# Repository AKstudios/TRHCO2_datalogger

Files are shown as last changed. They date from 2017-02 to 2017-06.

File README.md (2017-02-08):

# T/RH/CO2 data logger
A temperature, relative humidity and carbon dioxide data logger that stores time-stamped data in a microSD card at specific logging intervals.

<p align="center">
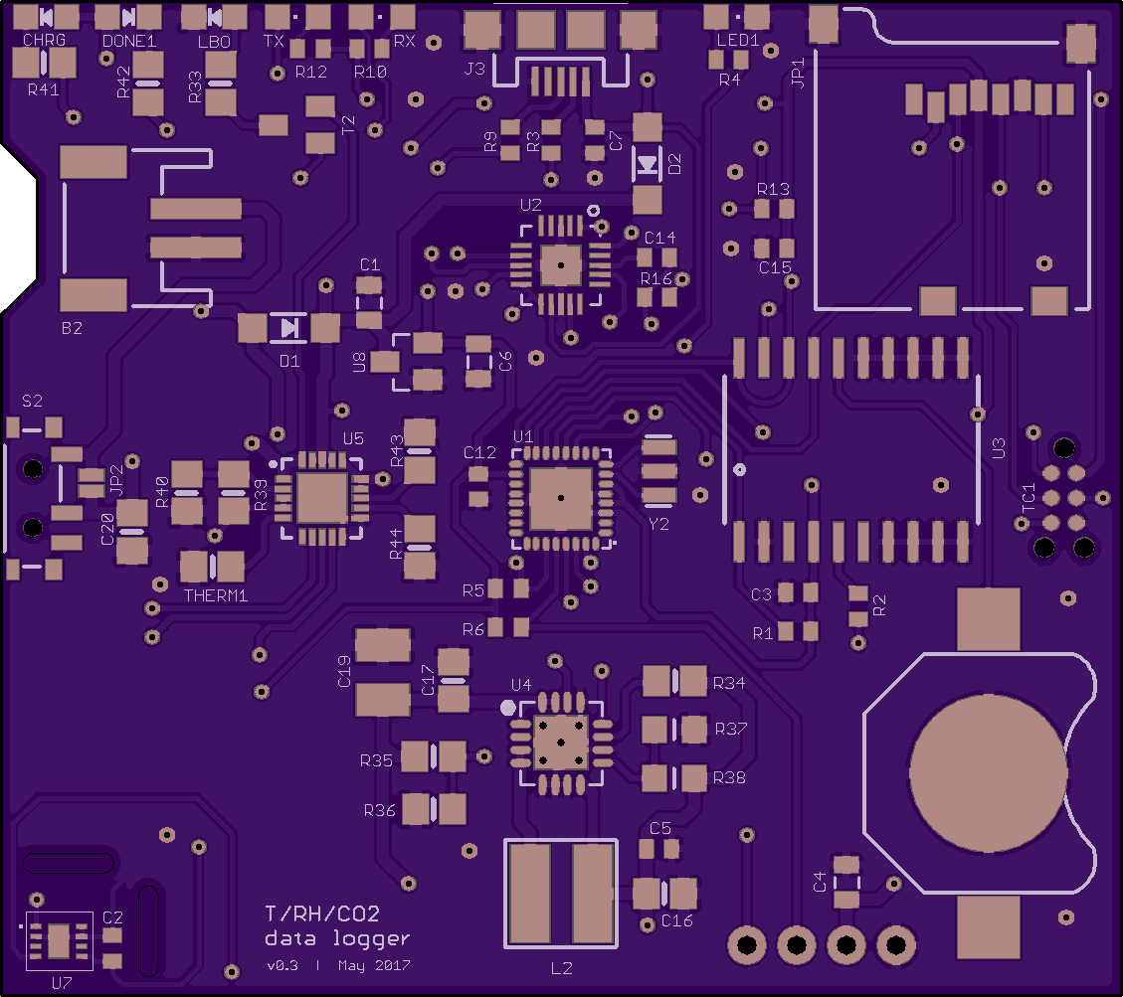
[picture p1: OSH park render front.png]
PIR datalogger - front
  
  <br></br>
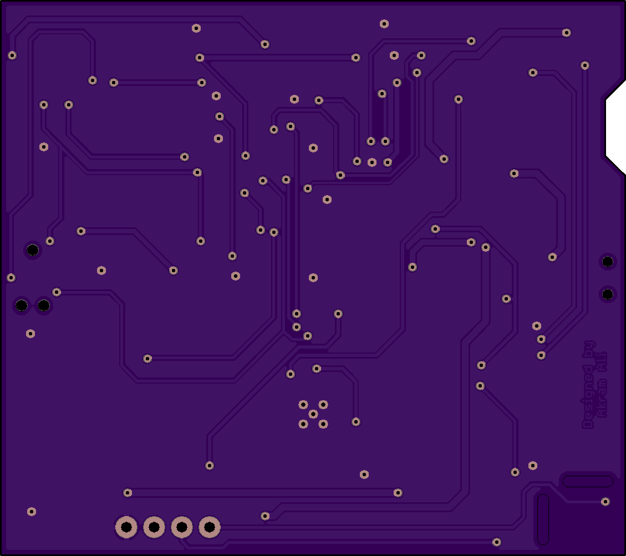
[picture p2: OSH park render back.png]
PIR datalogger - back
  
</p>

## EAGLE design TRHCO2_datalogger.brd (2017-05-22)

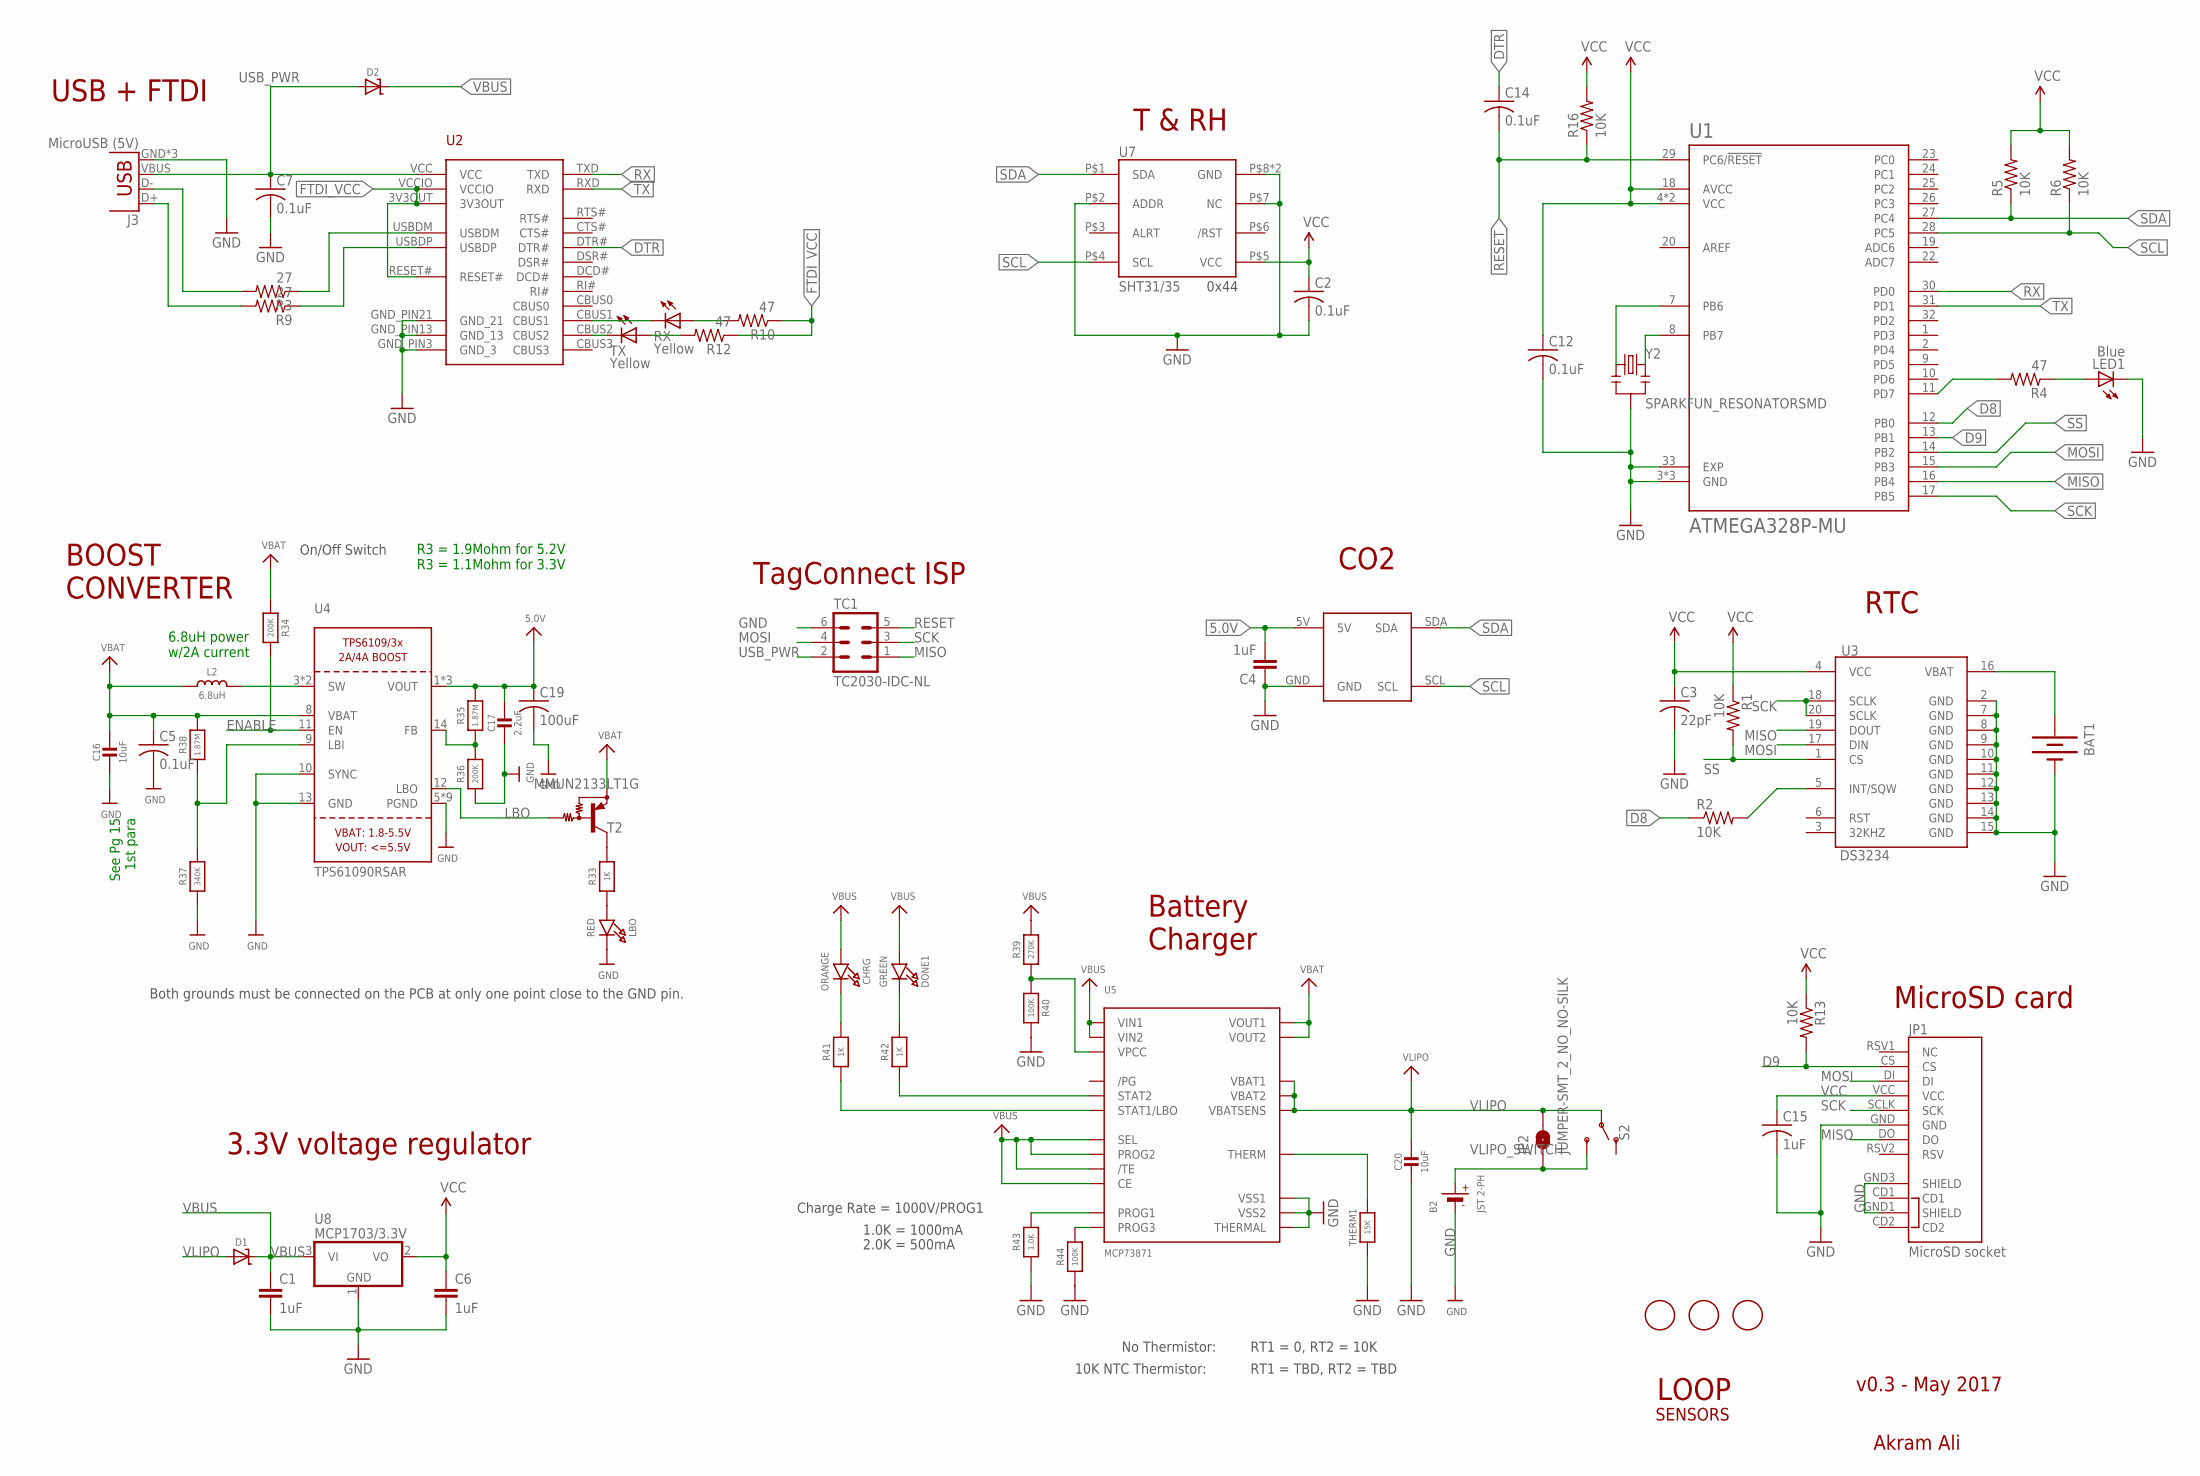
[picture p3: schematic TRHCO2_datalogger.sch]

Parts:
B2: JST 2-PH; JSTPH2
BAT1: BATTERY12MM; BATTCON_12MM; MPN 3000
C1, C4, C6: 1uF; 0805; MPN CC0805KKX7R7BB105
C2, C5, C7, C12, C14: 0.1uF; C0402
C3: 22pF; C0402
C15: 1uF; C0402
C16, C20: 10uF; 0805-NO
C17: 2.2uF; 0805-NO
C19: 100uF; C1210
CHRG: ORANGE; CHIPLED_0805_NOOUTLINE
D1, D2: MICROBUILDER_DIODE-SCHOTTKYSOD-123; MICROBUILDER_SOD-123
DONE1: GREEN; CHIPLED_0805_NOOUTLINE
J3: MicroUSB (5V); USB-MICROB; MPN CONN-09505
JP1: MicroSD socket; MICRO-SD-SOCKET-PP
JP2: JUMPER-SMT_2_NO_NO-SILK; SMT-JUMPER_2_NO_NO-SILK
L2: 6.8uH; INDUCTOR_5X5MM_TDK_VLC5045
LBO: RED; CHIPLED_0805_NOOUTLINE
LED1: Blue; CHIPLED_0805; MPN 150080BS75000
R1, R2, R5, R6, R13, R16: 10K; R0402
R3, R9: 27; R0402
R4, R10, R12: 47; R0402
R33, R41, R42: 1K; 0805-NO
R34, R36: 200K; 0805-NO
R35: 1.87M; 0805-NO
R37: 340K; _0805MP
R38: 1.87M; _0805MP
R39: 270K; 0805-NO
R40, R44: 100K; 0805-NO
R43: 1.0K; 0805-NO
RX: Yellow; CHIPLED_0805; MPN LG R971-KN-1
S2: SWITCH-SPDT-SMD-RIGHT-ANGLE; SWITCH_SPST_SMD_A
T2: MMUN2133LT1G; SC59-BEC
TC1: TC2030-IDC-NL
THERM1: 15K; 0805-NO
TX: Yellow; CHIPLED_0805; MPN LH R974-LP-1
U1: ATMEGA328P-MU; QFN50P500X500X100-33N
U2: FT231XQ-R; FTDI_FT231XQ-R_PACKAGE; MPN FT231XQ-R
U3: DS3234; MPN DS3234S#
U4: TPS61090RSAR; PVQFN-16
U5: MCP73871; QFN20_4MM
U6: K30-CO2-I2C
U7: SHT31/35; SHT3X; MPN SHT31-DIS-B
U8: MCP1703/3.3V; SOT23; MPN MCP1703T-2502E/CB
U$1, U$2, U$3: FIDUCIAL; FIDUCIAL_1MM
Y2: SPARKFUN_RESONATORSMD; SPARKFUN_RESONATOR-SMD

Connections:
5.0V: C4.2, C17.1, C19.1, R35.2, U4.1 (VOUT), U4.15 (VOUT), U4.16 (VOUT), U6.5V
D8: R2.1, U1.12 (PB0)
D9: JP1.CS, R13.2, U1.13 (PB1)
DTR: C14.1, U2.DTR#
ENABLE: R34.2, U4.11 (EN)
FTDI_VCC: R10.1, R12.1, U2.3V3OUT, U2.RESET#, U2.VCCIO
GND: B2.1 (-), BAT1.GND (-), C1.2, C2.2, C3.2, C4.1, C5.2, C6.2, C7.2, C12.2, C15.2, C16.2, C17.2, C19.2, C20.2, J3.GND, J3.MT1 (GND), J3.MT2 (GND), JP1.GND, JP1.GND1 (SHIELD), JP1.GND3 (SHIELD), LBO.C, LED1.C, R36.1, R37.1, R40.2, R43.1, R44.1, TC1.6, THERM1.1, U1.3 (GND), U1.5 (GND), U1.21 (GND), U1.33 (EXP), U2.GND_PIN3 (GND_3), U2.GND_PIN13 (GND_13), U2.GND_PIN21 (GND_21), U3.2 (GND), U3.7 (GND), U3.8 (GND), U3.9 (GND), U3.10 (GND), U3.11 (GND), U3.12 (GND), U3.13 (GND), U3.14 (GND), U3.15 (GND), U4.5 (PGND), U4.6 (PGND), U4.7 (PGND), U4.10 (SYNC), U4.13 (GND), U4.P$18 (PGND), U4.P$19 (PGND), U4.P$20 (PGND), U4.P$21 (PGND), U4.P$22 (PGND), U4.THERMAL (PGND), U5.P$10 (VSS1), U5.P$11 (VSS2), U5.P$21 (THERMAL), U6.GND, U7.P$2 (ADDR), U7.P$7 (NC), U7.P$8 (GND), U7.PAD (GND), U8.1 (GND), Y2.2
LBO: T2.B, U4.12 (LBO)
MISO: JP1.DO, TC1.1, U1.16 (PB4), U3.19 (DOUT)
MOSI: JP1.DI, TC1.4, U1.15 (PB3), U3.17 (DIN)
unnamed: R4.2, U1.11 (PD7)
unnamed: R2.2, U3.5 (INT/SQW)
unnamed: LED1.A, R4.1
unnamed: U1.8 (PB7), Y2.3
unnamed: U1.7 (PB6), Y2.1
unnamed: L2.P$2 (2), U4.3 (SW), U4.4 (SW)
unnamed: R37.2, R38.1, U4.9 (LBI)
unnamed: BAT1.PWR@1 (+), U3.16 (VBAT)
unnamed: LBO.A, R33.1
unnamed: RX.C, U2.CBUS1
unnamed: TX.C, U2.CBUS2
unnamed: R3.1, U2.USBDM
unnamed: R9.1, U2.USBDP
unnamed: R10.2, RX.A
unnamed: R35.1, R36.2, U4.14 (FB)
unnamed: R12.2, TX.A
unnamed: R33.2, T2.C
unnamed: R39.1, R40.1, U5.P$2 (VPCC)
unnamed: J3.D-, R3.2
unnamed: J3.D+, R9.2
unnamed: R42.1, U5.P$7 (STAT2)
unnamed: R41.1, U5.P$8 (STAT1/LBO)
unnamed: R43.2, U5.P$13 (PROG1)
unnamed: THERM1.2, U5.P$5 (THERM)
unnamed: DONE1.C, R42.2
unnamed: CHRG.C, R41.2
unnamed: R44.2, U5.P$12 (PROG3)
RESET: C14.2, R16.1, TC1.5, U1.29 (PC6/!RESET)
RX: U1.30 (PD0), U2.TXD
SCK: JP1.SCLK (SCK), TC1.3, U1.17 (PB5), U3.18 (SCLK), U3.20 (SCLK)
SCL: R6.1, U1.28 (PC5), U6.SCL, U7.P$4 (SCL)
SDA: R5.1, U1.27 (PC4), U6.SDA, U7.P$1 (SDA)
SS: R1.2, U1.14 (PB2), U3.1 (CS)
TX: U1.31 (PD1), U2.RXD
USB_PWR: C7.1, D2.A, J3.VBUS, TC1.2, U2.VCC
VBAT: C5.1, C16.1, L2.P$1 (1), R34.1, R38.2, T2.E, U4.8 (VBAT), U5.P$1 (VOUT1), U5.P$20 (VOUT2)
VBUS: C1.1, CHRG.A, D1.C, D2.C, DONE1.A, R39.2, U5.P$3 (SEL), U5.P$4 (PROG2), U5.P$9 (/TE), U5.P$17 (CE), U5.P$18 (VIN1), U5.P$19 (VIN2), U8.3 (VI)
VCC: C2.1, C3.1, C6.1, C12.1, C15.1, JP1.VCC, R1.1, R5.2, R6.2, R13.1, R16.2, U1.4 (VCC), U1.6 (VCC), U1.18 (AVCC), U3.4 (VCC), U7.P$5 (VCC), U8.2 (VO)
VLIPO: C20.1, D1.A, JP2.2, S2.2, U5.P$14 (VBAT1), U5.P$15 (VBAT2), U5.P$16 (VBATSENS)
VLIPO_SWITCH: B2.2 (+), JP2.1, S2.3 (S)

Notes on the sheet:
T & RH
3.3V voltage regulator
LOOP
Akram Ali
USB + FTDI
0x44
CO2
MicroSD card
RTC
v0.3 - May 2017
SENSORS
Both grounds must be connected on the PCB at only one point close to the GND pin.
On/Off Switch
See Pg 15 1st para
6.8uH power w/2A current
R3 = 1.9Mohm for 5.2V R3 = 1.1Mohm for 3.3V
Charge Rate = 1000V/PROG1
1.0K = 1000mA
2.0K = 500mA
No Thermistor:
10K NTC Thermistor:
RT1 = 0, RT2 = 10K
RT1 = TBD, RT2 = TBD
BOOST CONVERTER
Battery Charger
TagConnect ISP

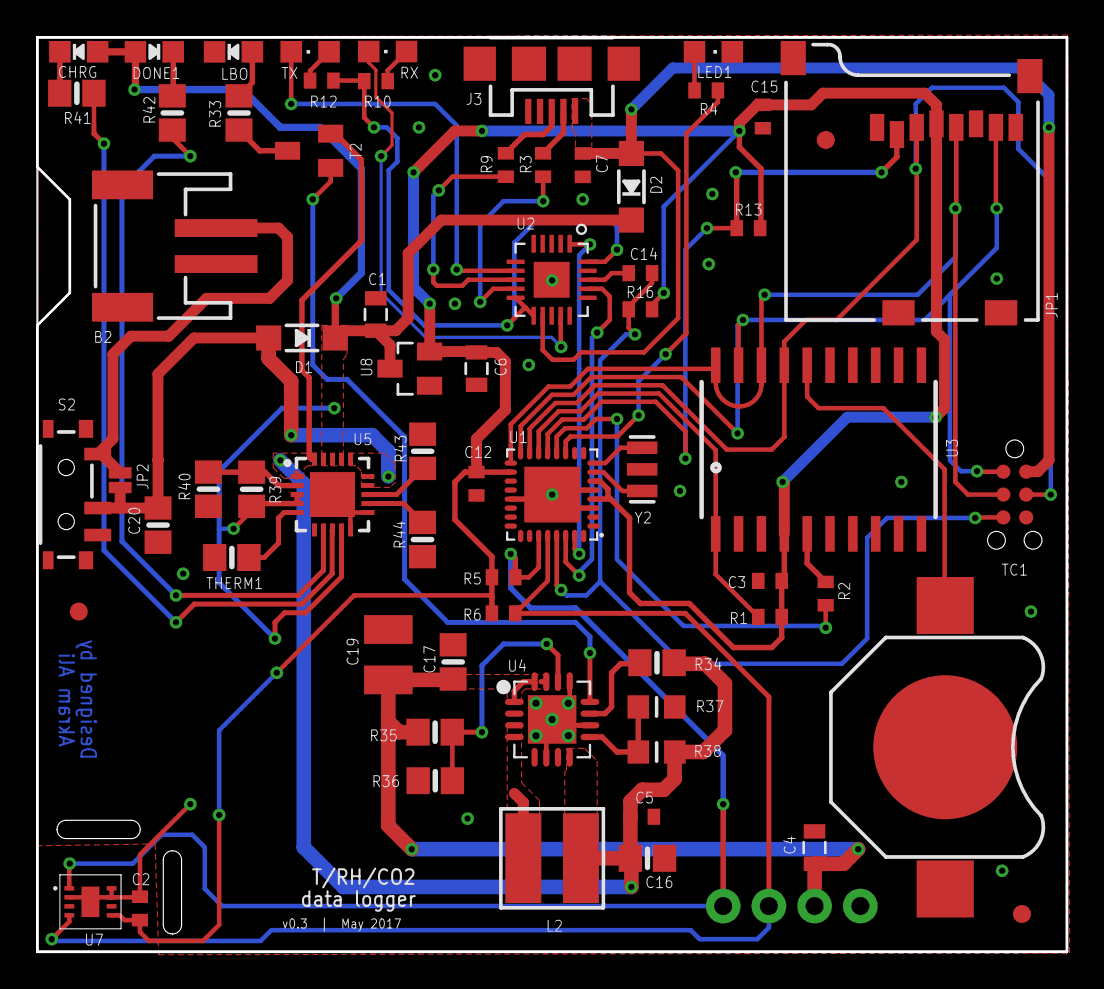
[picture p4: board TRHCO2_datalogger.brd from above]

Board: 2 copper layers, 57.2 x 50.8 mm, 67 parts (0 on the bottom side), 50 nets.

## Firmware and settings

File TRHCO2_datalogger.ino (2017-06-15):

// OSBSS T/RH/CO2 data logger based on SenseAir K-30 1% CO2 sensor and Sensirion SHT35 sensor
// read interval stored in config.txt
// Last edited on June 15, 2017 - Arduino IDE 1.8.2, Latest SdFat library

#include <EEPROM.h>
#include <Wire.h>
#include <SPI.h>
#include <DS3234lib3.h>         // https://github.com/OSBSS/DS3234lib3
#include <PowerSaver.h>         // https://github.com/OSBSS/PowerSaver
#include "SdFat.h"              // https://github.com/greiman/SdFat
#include "Adafruit_SHT31.h"     // https://github.com/adafruit/Adafruit_SHT31

// Launch Variables   ******************************
long interval = 30;  // set logging interval in SECONDS, eg: set 300 seconds for an interval of 5 mins
int dayStart = 14, hourStart = 13, minStart = 41;    // define logger start time: day of the month, hour, minute
char filename[15] = "data.csv";    // Set filename Format: "12345678.123". Cannot be more than 8 characters in length, contain spaces or begin with a number
int data; // read each byte of data from sd card and store here

// Global objects and variables   ******************************
Adafruit_SHT31 sht31 = Adafruit_SHT31();
PowerSaver chip;  	// declare object for PowerSaver class
DS3234 RTC;    // declare object for DS3234 class
SdFat sd;
SdFile myFile;

//#define POWER 3    // pin 3 supplies power to microSD card breakout
#define LED 7  // pin 7 controls LED
int chipSelect = 9; // pin 9 is CS pin for MicroSD breakout

int CO2ppm = 0;
int _CO2ppm;

// ISR ****************************************************************
ISR(PCINT0_vect)  // Interrupt Vector Routine to be executed when pin 8 receives an interrupt.
{
  //PORTB ^= (1<<PORTB1);
  asm("nop");
}

// setup ****************************************************************
void setup()
{
  Serial.begin(19200); // open serial at 19200 bps
  Serial.flush(); // clear the buffer
  delay(5);
  
  Serial.println("Setup");
  delay(10);
  
  pinMode(LED, OUTPUT); // set output pins
  Wire.begin();  // initialize I2C using Wire.h library
  delay(1);    // give some delay to ensure things are initialized properly

  if (! sht31.begin(0x44))  // Set to 0x45 for alternate i2c addr
  {   
    Serial.println("Couldn't find SHT31/35");
    delay(10);
  }
  
  Serial.println(RTC.timeStamp());    // get date and time from RTC
  delay(10);

  if(!sd.begin(chipSelect, SPI_HALF_SPEED))  // initialize microSD card
  {
    SDcardError(3);
  }
  else
  {
    // open the file for write at end like the Native SD library
    if(!myFile.open(filename, O_RDWR | O_CREAT | O_AT_END))
    {
      SDcardError(2);
    }

    else
    {    
      myFile.println();
      myFile.println("Date/Time,Temp(C),RH(%),CO2(ppm)");
      myFile.println();
      myFile.close();
      
      digitalWrite(LED, HIGH);
      delay(10);
      digitalWrite(LED, LOW);
    }
  }
  
  if(!myFile.open("config.txt", O_READ))  // open config.txt and read logging interval
  {
    Serial.println("config.txt file error. Setting default interval to 30 seconds.");
    delay(50);
  }

  else
  {
    char interval_array[5]; // should be able to store 5 digit maximum (86,400 seconds = 24 hours)
    int i=0; // index of array
    long _interval;  // logging interval read from file
    boolean error_flag = false;
    
    while(1)
    {
      data = myFile.read();  // read next byte in file
      
      if(data < 0)  // if no bytes remaining, myFile.read() returns -1
        break;      // exit loop

      if(data >= 48 && data <= 57) // check if data is digits ONLY (between 0-9). ASCII value of 0 = 48; 9 = 57
        interval_array[i] = (char)data;  // store digit in char array
      else  // if any other charecter other than numbers 0-9
      {
        error_flag = true;
        break;
      }
      
      i++; // increment index of array by 1
      if(i>5)  // only read the first 5 digits in file. Ignore all other values
        break;
    }
    myFile.close();  // close file - very important!
    sscanf(interval_array, "%ld", &_interval);  // "%ld" will convert array to long (use "%d" to convert to int)
    
    if(_interval <= 0 || _interval > 86400 || error_flag == true)
    {
      Serial.println("Incorrect format or out of bounds. Must be a number between 1 and 86,400 seconds. Setting default interval to 30 seconds.");
      delay(50);
    }
    else
    {
      interval = _interval;
      Serial.print("New logging interval set: ");
      Serial.println(interval);
      delay(50);
    }
  }
  RTC.setNewAlarm(interval);
  chip.sleepInterruptSetup();    // setup sleep function on the ATmega328p. Power-down mode is used here
  delay(10);
}


// loop ****************************************************************
void loop()
{  
  chip.turnOffADC();    // turn off ADC to save power
  chip.turnOffSPI();  // turn off SPI bus to save power
  chip.turnOffWDT();  // turn off WatchDog Timer to save power (does not work for Pro Mini - only works for Uno)
  chip.turnOffBOD();    // turn off Brown-out detection to save power
  
  
  chip.goodNight();    // put processor in extreme power down mode - GOODNIGHT!
                       // this function saves previous states of analog pins and sets them to LOW INPUTS
                       // average current draw on Mini Pro should now be around 0.195 mA (with both onboard LEDs taken out)
                       // Processor will only wake up with an interrupt generated from the RTC, which occurs every logging interval
                       
  chip.turnOnADC();    // enable ADC after processor wakes up
  chip.turnOnSPI();   // turn on SPI bus once the processor wakes up
  delay(1);    // important delay to ensure SPI bus is properly activated
  
  RTC.alarmFlagClear();    // clear alarm flag
  
  RTC.checkDST();  // check and account for Daylight Saving Time in US

  String time = RTC.timeStamp();    // get date and time from RTC
  Serial.println(time);
  delay(10);
  
  float t = sht31.readTemperature();
  float h = sht31.readHumidity();
  
  CO2ppm = GetCO2(0x68); // default address for K-30 CO2 sensor is 0x68
  
  // account for dropped values
  if(CO2ppm > 0)
    _CO2ppm = CO2ppm;
  if(CO2ppm <=0)
    CO2ppm = _CO2ppm;

  Serial.print("Temperature: ");
  Serial.print(t);
  Serial.println(" C");
  
  Serial.print("Humidity: ");
  Serial.print(h); 
  Serial.println(" %");
  
  Serial.print("CO2: ");
  Serial.print(CO2ppm);
  Serial.println(" ppm");
  
  Serial.println();
  delay(50); // give some delay to ensure CO2 data is properly received from sensor
  

  if(!sd.begin(chipSelect, SPI_HALF_SPEED))
  {
    SDcardError(3);
  }
  else
  {
    if(!myFile.open(filename, O_RDWR | O_CREAT | O_AT_END))
    {
      SDcardError(2);
    }
  
    else
    {
      myFile.print(time);
      myFile.print(",");
      myFile.print(t);
      myFile.print(",");
      myFile.print(h);
      myFile.print(",");
      myFile.println(CO2ppm);
      myFile.close();
      
      digitalWrite(LED, HIGH);
      delay(10);
      digitalWrite(LED, LOW);
    }
  }
  
  RTC.setNextAlarm();      //set next alarm before sleeping
  delay(1);
}

// Get CO2 concentration ****************************************************************
int GetCO2(int address)
{
  byte recieved[4] = {0,0,0,0}; // create an array to store bytes received from sensor
  
  Wire.beginTransmission(address);
  Wire.write(0x22);
  Wire.write(0x00);
  Wire.write(0x08);
  Wire.write(0x2A);
  Wire.endTransmission();
  delay(20); // give delay to ensure transmission is complete
  
  Wire.requestFrom(address,4);
  delay(10);
  
  byte i=0;
  while(Wire.available())
  {
    recieved[i] = Wire.read();
    i++;
  }
  
  byte checkSum = recieved[0] + recieved[1] + recieved[2];
  CO2ppm = (recieved[1] << 8) + recieved[2];
  
  if(checkSum == recieved[3])
    return CO2ppm;
  else
    return -1;
}

// SD card Error response ****************************************************************
void SDcardError(int n)
{
    for(int i=0;i<n;i++)   // blink LED 3 times to indicate SD card write error; 2 to indicate file read error
    {
      digitalWrite(LED, HIGH);
      delay(50);
      digitalWrite(LED, LOW);
      delay(150);
    }
}

//****************************************************************

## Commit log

2017-01-13 Added EAGLE files
    [TRHCO2_datalogger.brd, TRHCO2_datalogger.sch]
2017-01-17 Completed v0.1 design
    Routed all traces
    [TRHCO2_datalogger.brd, TRHCO2_datalogger.sch]
2017-01-18 Added D battery input headers
    Requires boost converter (https://www.sparkfun.com/products/10255) to allow 2 D batteries to supply at least 3V and get output 5V, 500mA
    [TRHCO2_datalogger.brd, TRHCO2_datalogger.sch]
2017-01-19 Traces adjusted
    Cleared some spacing between traces and vias
    Added MPN for some components
    [TRHCO2_datalogger.brd, TRHCO2_datalogger.sch]
2017-01-19 Minor fixes
    [TRHCO2_datalogger.brd, TRHCO2_datalogger.sch]
2017-02-08 v0.2 - Major fixes
    - Flipped header for LiPo boost. + and - are now facing up
    - Added pullup on DS3234 clock - so there is no interference while
    flashing bootloader (can be removed by desoldering jumper)
    - Added NPN transistor in the circuit to switch microSD card on/off for
    previous adaptations of Sdfat library
    - Routed CS pin of microSD card to ISP header for debug when necessary
    - Added 1uF capacitor to microSD's supply
    - Minor bug fixes and trace rearrangments
    [TRHCO2_datalogger.sch]
2017-02-15 v0.1 firmware added
    Use latest Arduino IDE (1.8.1) and latest Sdfat library
2017-05-21 v0.3 - major update
    - Added boost converter (TPS61090)
    - Added switch for battery
    - Replaced ISP header with TagConnect pins
    - Added pullups on all SPI devices
    - Removed transistor from sensors and SD card
    - Removed jumper @ DS3234 pull up
    - Battery groove at edge
    - Added LEDs for status indication
    - Changed CO2 sensor dimensions to be exact
    - Align USB port in center
    - Removed PWR LED from booster circuir
    - Changed some parts to 0402
    - Replaced 16 MHz footprint
    - Reroute all traces
    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
    [TRHCO2_datalogger.brd, TRHCO2_datalogger.sch]
2017-05-22 Added power plane
    Adjusted traces, added power planes, some other minor trace adjustments
    [TRHCO2_datalogger.brd, TRHCO2_datalogger.sch]
2017-06-15 Add units to serial print
2018-08-13 Revert "update"
    This reverts commit 3fd739265b7c9a937414b5746fef9af12a5aee94.
    [TRHHCHO_datalogger.brd]
2018-08-13 Revert "Initial commit"
    This reverts commit c60d50e7691b51f36b2304322911fcaf5220ad07.
    [TRHCO2_datalogger.brd, TRHCO2_datalogger.sch, TRHHCHO_datalogger.brd]
2018-08-13 Revert "Add units to serial print"
    This reverts commit 42bc8d94add604d970789fbf07ac64797589f6a5.
    [TRHCO2_datalogger.ino]

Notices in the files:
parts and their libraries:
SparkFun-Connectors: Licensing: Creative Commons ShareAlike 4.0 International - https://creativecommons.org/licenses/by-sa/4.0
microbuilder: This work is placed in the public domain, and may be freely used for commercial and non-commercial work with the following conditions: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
